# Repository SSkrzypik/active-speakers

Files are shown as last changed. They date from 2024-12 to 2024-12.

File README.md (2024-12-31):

The project involves active speakers inspired by the Tonsil Maestro S. The power amplifier driving the speakers consists of four TDA7294 chips. For the crossover network and sound tone adjustments, a DSP Adau1701 is used. The power supply is sourced from a toroidal transformer, and the section is enhanced with an EMI filter and a soft-start circuit. Additionally, the master speaker features an extra board that controls an OLED display and serves as a Bluetooth audio source.

qW7aE1r
IkFJe0s
2Np26g0
At0ftzc

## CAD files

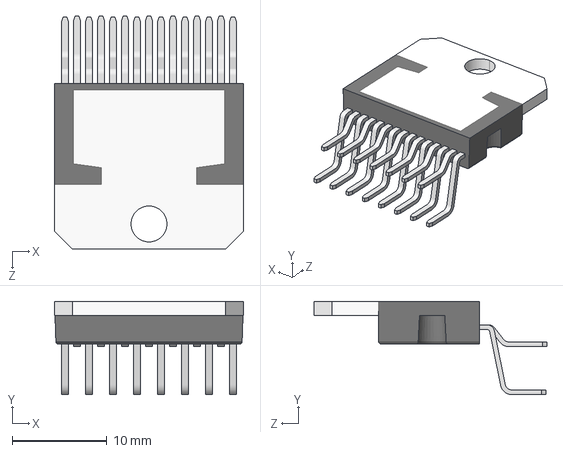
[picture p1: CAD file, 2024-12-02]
hardware/amplifier/3d/MULTIWATT15.STEP
20.0 x 9.88 x 24.6 mm

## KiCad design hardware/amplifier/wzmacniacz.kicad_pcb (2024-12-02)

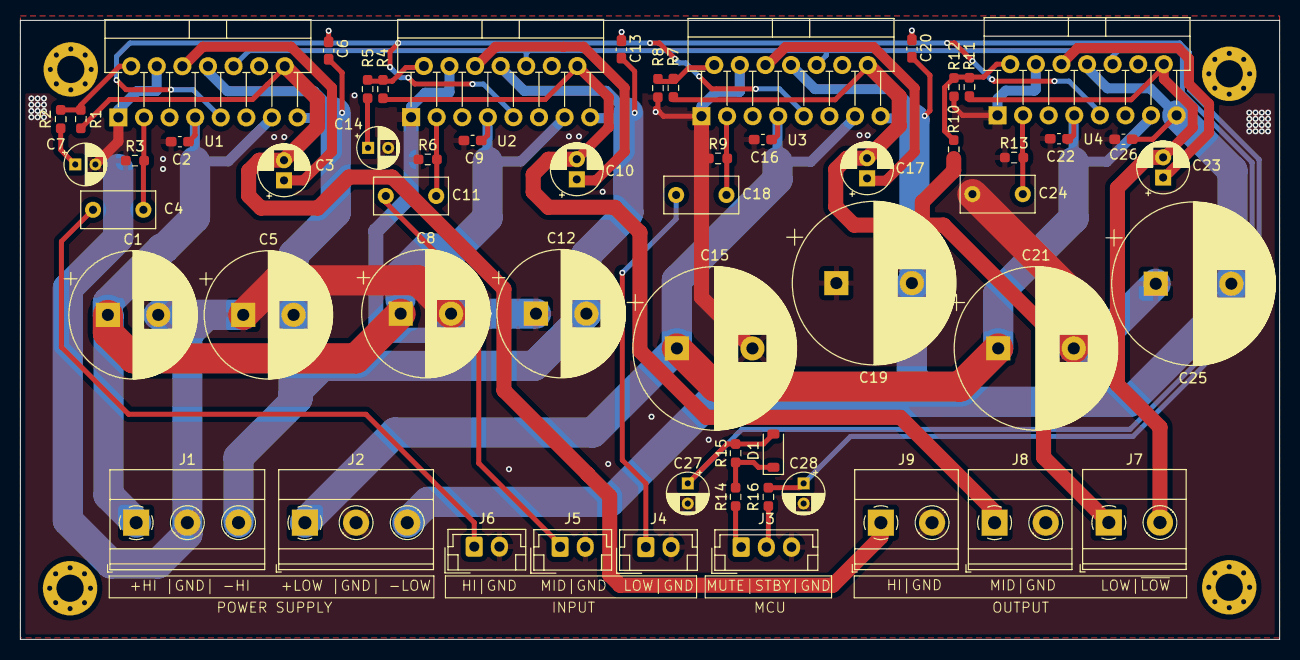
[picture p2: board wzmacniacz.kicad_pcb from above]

Board: 2 copper layers, 125.0 x 61.4 mm, 62 parts (0 on the bottom side), 31 nets.

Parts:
C1, C5, C8, C12: 1000uF; CP_Radial_D12.5mm_P5.00mm
C2, C6, C9, C13, C16, C20, C22, C26: 100nF; C_0603_1608Metric_Pad1.08x0.95mm_HandSolder
C3, C10, C17, C23: 22uF; CP_Radial_D5.0mm_P2.00mm
C4, C11: 470nF; C_Rect_L7.2mm_W3.5mm_P5.00mm_FKS2_FKP2_MKS2_MKP2
C7, C14, C27, C28: 22uF; CP_Radial_D4.0mm_P2.00mm
C15, C19, C21, C25: 2200uF; CP_Radial_D16.0mm_P7.50mm
C18, C24: 560nF; C_Rect_L7.2mm_W3.5mm_P5.00mm_FKS2_FKP2_MKS2_MKP2
D1: 1N4148WT; D_SOD-123
H1, H2, H3, H4: MountingHole; MountingHole_2.7mm_Pad_Via
J1, J2: Conn_01x03; TerminalBlock_Phoenix_MKDS-1,5-3-5.08_1x03_P5.08mm_Horizont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
J3: Conn_01x03; JST_EH_B3B-EH-A_1x03_P2.50mm_Vertical
J4, J5, J6: Conn_01x02; JST_EH_B2B-EH-A_1x02_P2.50mm_Vertical
J7, J8, J9: Conn_01x02; TerminalBlock_Phoenix_MKDS-1,5-2-5.08_1x02_P5.08mm_Horizont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
R1, R3, R4, R6, R7, R9, R10, R11, R13, R16: 22K; R_0603_1608Metric_Pad0.98x0.95mm_HandSolder
R2, R5, R8, R12: 680; R_0603_1608Metric_Pad0.98x0.95mm_HandSolder
R14: 10K; R_0603_1608Metric_Pad0.98x0.95mm_HandSolder
R15: 30K; R_0603_1608Metric_Pad0.98x0.95mm_HandSolder
U1, U2, U3, U4: TDA7294; TO-220-15_P2.54x2.54mm_StaggerOdd_Lead4.58mm_Vertical

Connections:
+VS_HI/MID: C1.1, C2.2, C8.1, C9.2, J1.1, U1.7 (+Vs), U1.13 (+Vs), U2.7 (+Vs), U2.13 (+Vs)
+VS_LOW: C15.1, C16.2, C21.1, C22.2, J2.1, U3.7 (+Vs), U3.13 (+Vs), U4.7 (+Vs), U4.13 (+Vs)
-VS_HI/MID: C5.2, C6.2, C12.2, C13.2, J1.3, U1.8 (-Vs), U1.15 (-Vs), U2.8 (-Vs), U2.15 (-Vs)
-VS_LOW: C19.2, C20.2, C25.2, C26.2, J2.3, U3.8 (-Vs), U3.15 (-Vs), U4.8 (-Vs), U4.15 (-Vs)
/CTRL_MUTE: J3.1, R14.1
/CTRL_STBY: J3.2, R16.2
/IN_HIGH: C4.1, J6.1
/IN_LOW: C18.1, J4.1
/IN_MID: C11.1, J5.1
/MUTE: C27.1, D1.2 (A), R15.2, U1.10 (MUTE), U2.10 (MUTE), U3.10 (MUTE), U4.10 (MUTE)
/OUT_HIGH: C3.2, J9.1, R1.1, U1.14
/OUT_LOW+: C17.2, J7.1, R7.1, R10.1, U3.14
/OUT_LOW-: C23.2, J7.2, R11.1, U4.14
/OUT_MID: C10.2, J8.1, R4.1, U2.14
/STBY: C28.1, R16.1, U1.9 (STBY), U2.9 (STBY), U3.9 (STBY), U4.9 (STBY)
GND: C1.2, C2.1, C5.1, C6.1, C7.2, C8.2, C9.1, C12.1, C13.1, C14.2, C15.2, C16.1, C19.1, C20.1, C21.2, C22.1, C24.1, C25.1, C26.1, C27.2, C28.2, J1.2, J2.2, J3.3, J4.2, J5.2, J6.2, J8.2, J9.2, R3.1, R6.1, R8.1, R9.1, R12.1, R13.1, U1.1 (SGND), U1.4 (SIG_GND), U2.1 (SGND), U2.4 (SIG_GND), U3.1 (SGND), U3.4 (SIG_GND), U4.1 (SGND), U4.4 (SIG_GND)
unnamed: C7.1, R2.1
unnamed: C14.1, R5.1
unnamed: D1.1 (K), R14.2, R15.1
unnamed: C4.2, R3.2, U1.3 (+)
unnamed: R1.2, R2.2, U1.2 (-)
unnamed: C3.1, U1.6 (BOOT)
unnamed: C11.2, R6.2, U2.3 (+)
unnamed: R4.2, R5.2, U2.2 (-)
unnamed: C10.1, U2.6 (BOOT)
unnamed: C18.2, R9.2, U3.3 (+)
unnamed: R7.2, R8.2, U3.2 (-)
unnamed: C17.1, U3.6 (BOOT)
unnamed: C24.2, R13.2, U4.3 (+)
unnamed: R10.2, R11.2, R12.2, U4.2 (-)
unnamed: C23.1, U4.6 (BOOT)

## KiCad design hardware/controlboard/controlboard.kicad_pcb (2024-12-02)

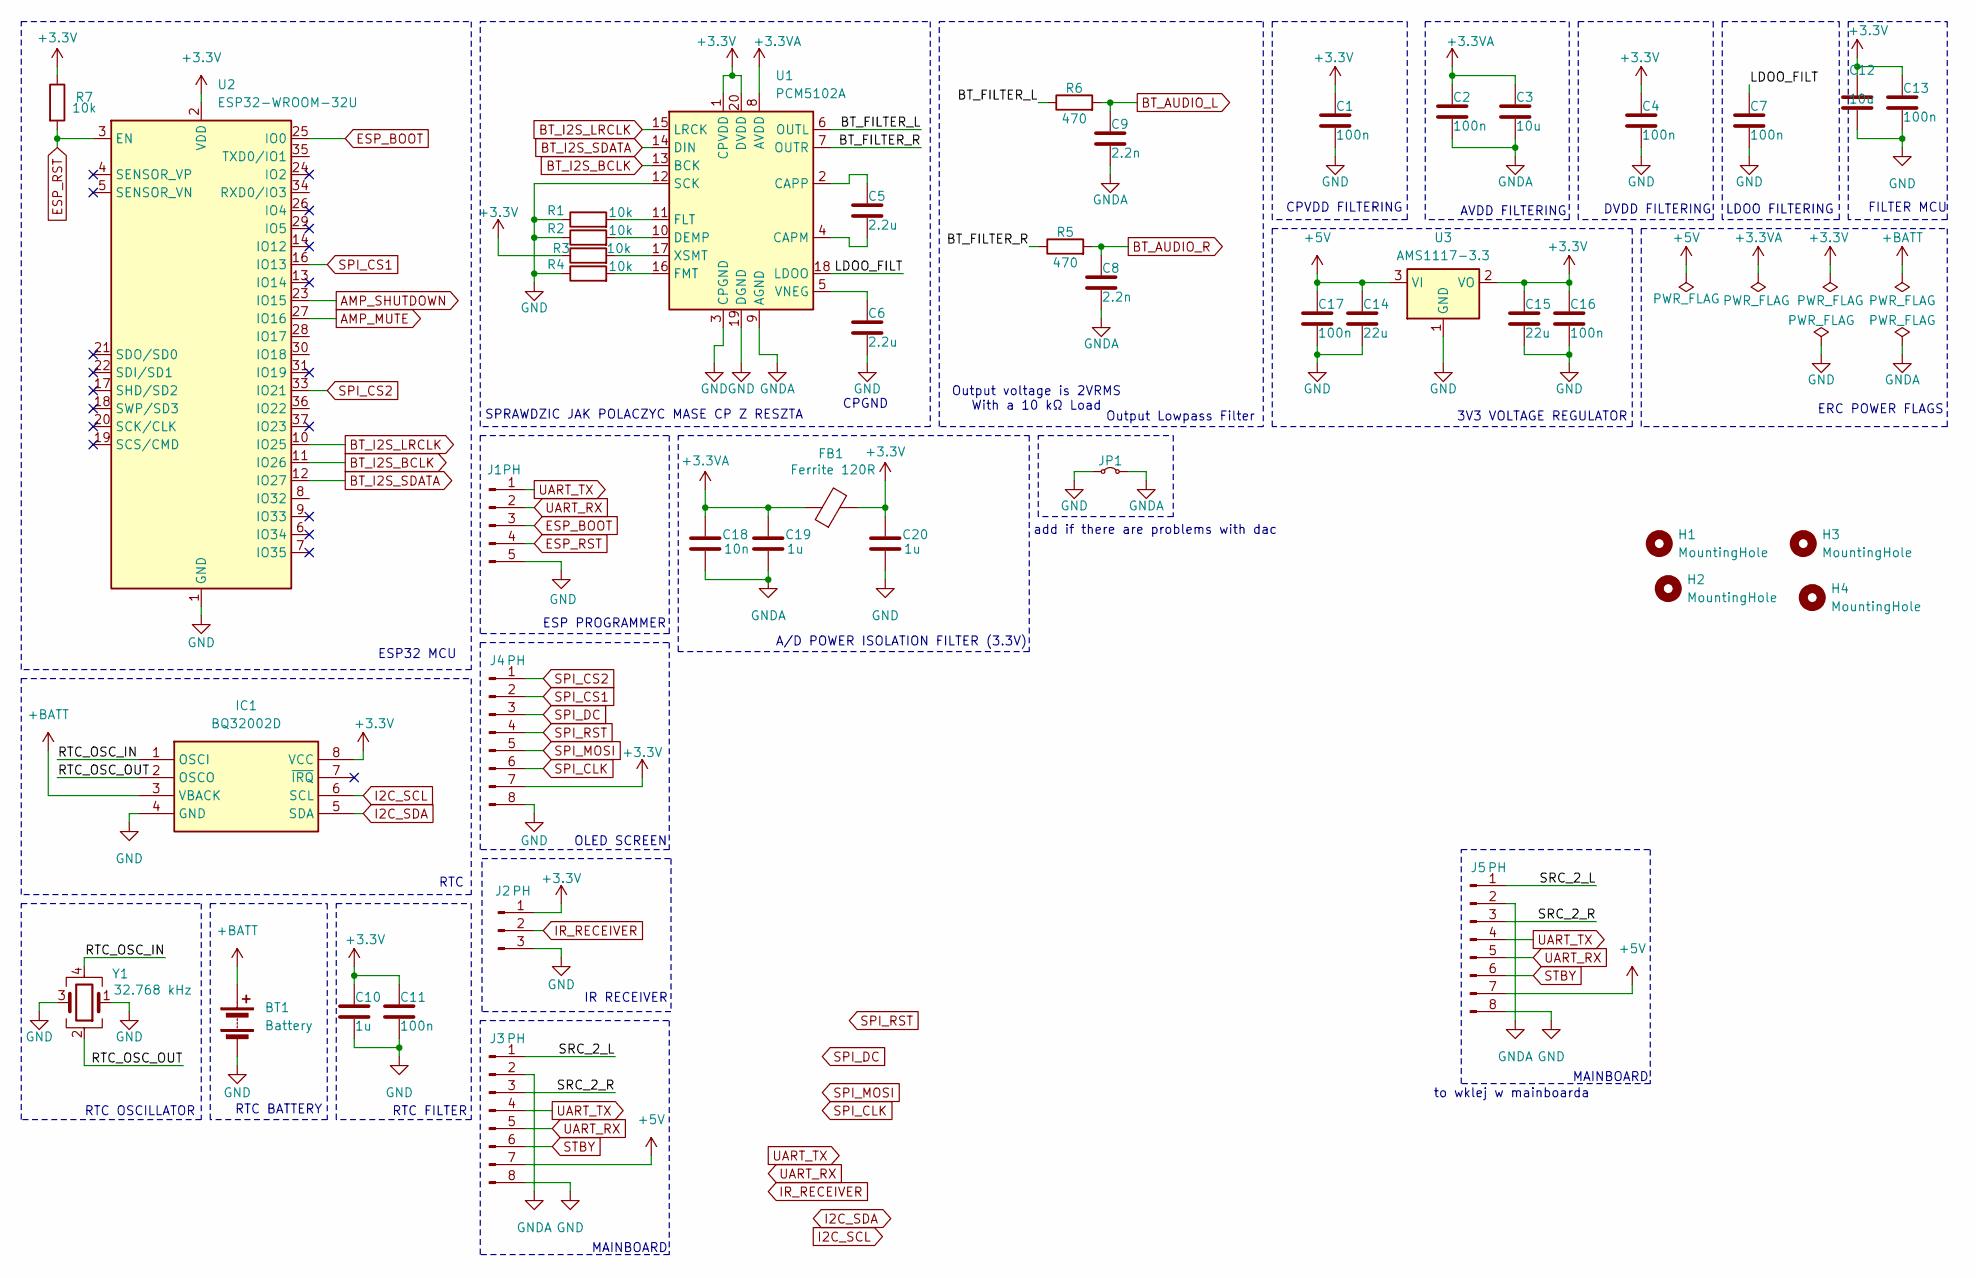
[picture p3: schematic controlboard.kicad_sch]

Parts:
BT1: Battery; BatteryHolder_LINX_BAT-HLD-012-SMT
C1, C2, C4, C7, C11, C13, C16, C17: 100n; C_0603_1608Metric_Pad1.08x0.95mm_HandSolder
C3, C12: 10u; C_0603_1608Metric_Pad1.08x0.95mm_HandSolder
C5, C6: 2.2u; C_0603_1608Metric_Pad1.08x0.95mm_HandSolder
C8, C9: 2.2n; C_0603_1608Metric_Pad1.08x0.95mm_HandSolder
C10, C19, C20: 1u; C_0603_1608Metric_Pad1.08x0.95mm_HandSolder
C14, C15: 22u; C_0603_1608Metric_Pad1.08x0.95mm_HandSolder
C18: 10n; C_0603_1608Metric_Pad1.08x0.95mm_HandSolder
FB1: Ferrite 120R; L_0805_2012Metric_Pad1.05x1.20mm_HandSolder
H1, H2, H3, H4: MountingHole; MountingHole_3.2mm_M3
IC1: BQ32002D; SOIC-8_3.9x4.9mm_P1.27mm; Mouser Part Number 595-BQ32002D
J1: PH; JST_PH_B5B-PH-K_1x05_P2.00mm_Vertical
J2: PH; JST_PH_B3B-PH-K_1x03_P2.00mm_Vertical
J3, J4: PH; JST_PH_B8B-PH-K_1x08_P2.00mm_Vertical
J5: PH
JP1: Jumper_2_Small_Bridged; R_1210_3225Metric_Pad1.30x2.65mm_HandSolder
R1, R2, R3, R4, R7: 10k; R_0603_1608Metric_Pad0.98x0.95mm_HandSolder
R5, R6: 470; R_0603_1608Metric_Pad0.98x0.95mm_HandSolder
U1: PCM5102A; TSSOP-20_4.4x6.5mm_P0.65mm
U2: ESP32-WROOM-32U
U3: AMS1117-3.3; SOT-223-3_TabPin2
Y1: 32.768 kHz; Crystal_SMD_7050-4Pin_7.0x5.0mm

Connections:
+3.3V: C1.1, C4.1, C10.1, C11.1, C12.1, C13.1, C15.1, C16.1, C20.1, FB1.2, IC1.8 (VCC), J2.1, J4.7, R3.1, R7.1, U1.1 (CPVDD), U1.20 (DVDD), U2.2 (VDD), U3.2 (VO)
+3.3VA: C2.1, C3.1, C18.1, C19.1, FB1.1, U1.8 (AVDD)
+5V: C14.1, C17.1, J3.7, J5.7, U3.3 (VI)
+BATT: BT1.1 (+), IC1.3 (VBACK)
/BT_FILTER_L: R6.1, U1.6 (OUTL)
/BT_FILTER_R: R5.1, U1.7 (OUTR)
/LDOO_FILT: C7.1, U1.18 (LDOO)
/RTC_OSC_IN: IC1.1 (OSCI), Y1.4
/RTC_OSC_OUT: IC1.2 (OSCO), Y1.2
/SRC_2_L: J3.1, J5.1
/SRC_2_R: J3.3, J5.3
AMP_MUTE: U2.27 (IO16)
AMP_SHUTDOWN: U2.23 (IO15)
BT_AUDIO_L: C9.1, R6.2
BT_AUDIO_R: C8.1, R5.2
BT_I2S_BCLK: U1.13 (BCK), U2.11 (IO26)
BT_I2S_LRCLK: U1.15 (LRCK), U2.10 (IO25)
BT_I2S_SDATA: U1.14 (DIN), U2.12 (IO27)
ESP_BOOT: J1.3, U2.25 (IO0)
ESP_RST: J1.4, R7.2, U2.3 (EN)
GND: BT1.2 (-), C1.2, C4.2, C6.2, C7.2, C10.2, C11.2, C12.2, C13.2, C14.2, C15.2, C16.2, C17.2, C20.2, IC1.4 (GND), J1.5, J2.3, J3.8, J4.8, J5.8, JP1.1 (A), R1.1, R2.1, R4.1, U1.3 (CPGND), U1.12 (SCK), U1.19 (DGND), U2.1 (GND), U2.15 (GND), U2.38 (GND), U2.39 (GND), U3.1 (GND), Y1.1, Y1.3
GNDA: C2.2, C3.2, C8.2, C9.2, C18.2, C19.2, J3.2, J5.2, JP1.2 (B), U1.9 (AGND)
I2C_SCL: IC1.6 (SCL)
I2C_SDA: IC1.5 (SDA)
IR_RECEIVER: J2.2
unnamed: C5.2, U1.4 (CAPM)
unnamed: C5.1, U1.2 (CAPP)
unnamed: R2.2, U1.10 (DEMP)
unnamed: R1.2, U1.11 (FLT)
unnamed: R4.2, U1.16 (FMT)
unnamed: C6.1, U1.5 (VNEG)
unnamed: R3.2, U1.17 (XSMT)
SPI_CLK: J4.6
SPI_CS1: J4.2, U2.16 (IO13)
SPI_CS2: J4.1, U2.33 (IO21)
SPI_DC: J4.3
SPI_MOSI: J4.5
SPI_RST: J4.4
STBY: J3.6, J5.6
UART_RX: J1.2, J3.5, J5.5
UART_TX: J1.1, J3.4, J5.4

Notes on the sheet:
ESP32 MCU
ERC POWER FLAGS
RTC FILTER
AVDD FILTERING
ESP PROGRAMMER
MAINBOARD
FILTER MCU
Output voltage is 2VRMS With a 10 kΩ Load
to wklej w mainboarda
RTC OSCILLATOR
3V3 VOLTAGE REGULATOR
RTC BATTERY
RTC
CPGND
add if there are problems with dac
OLED SCREEN
IR RECEIVER
Output Lowpass Filter
CPVDD FILTERING
LDOO FILTERING
SPRAWDZIC JAK POLACZYC MASE CP Z RESZTA
DVDD FILTERING
A/D POWER ISOLATION FILTER (3.3V)

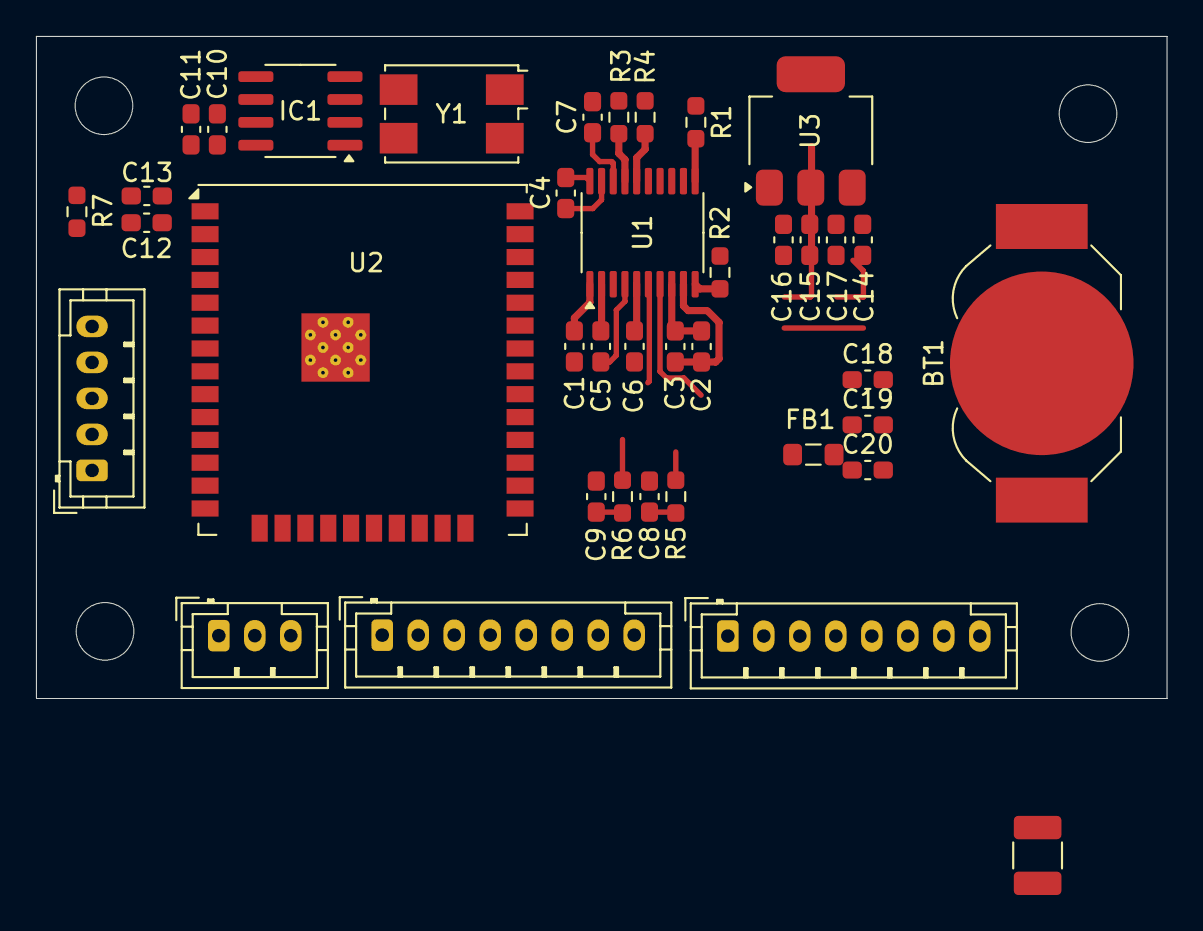
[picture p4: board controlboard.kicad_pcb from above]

Board: 2 copper layers, 62.8 x 36.8 mm, 43 parts (0 on the bottom side), 29 nets.

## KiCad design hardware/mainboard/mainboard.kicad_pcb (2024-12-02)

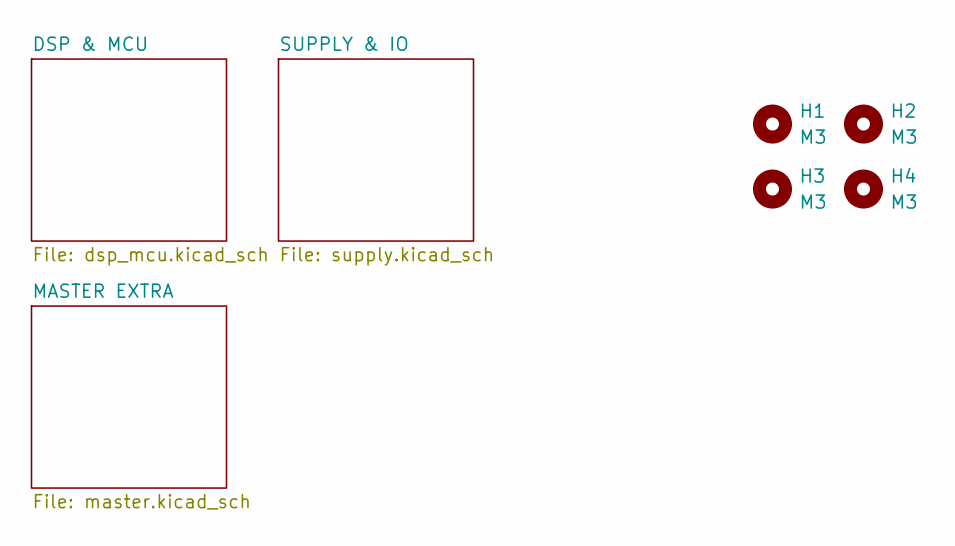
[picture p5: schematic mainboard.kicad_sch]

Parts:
H1, H2, H3, H4: M3; MountingHole_2.7mm_M2.5

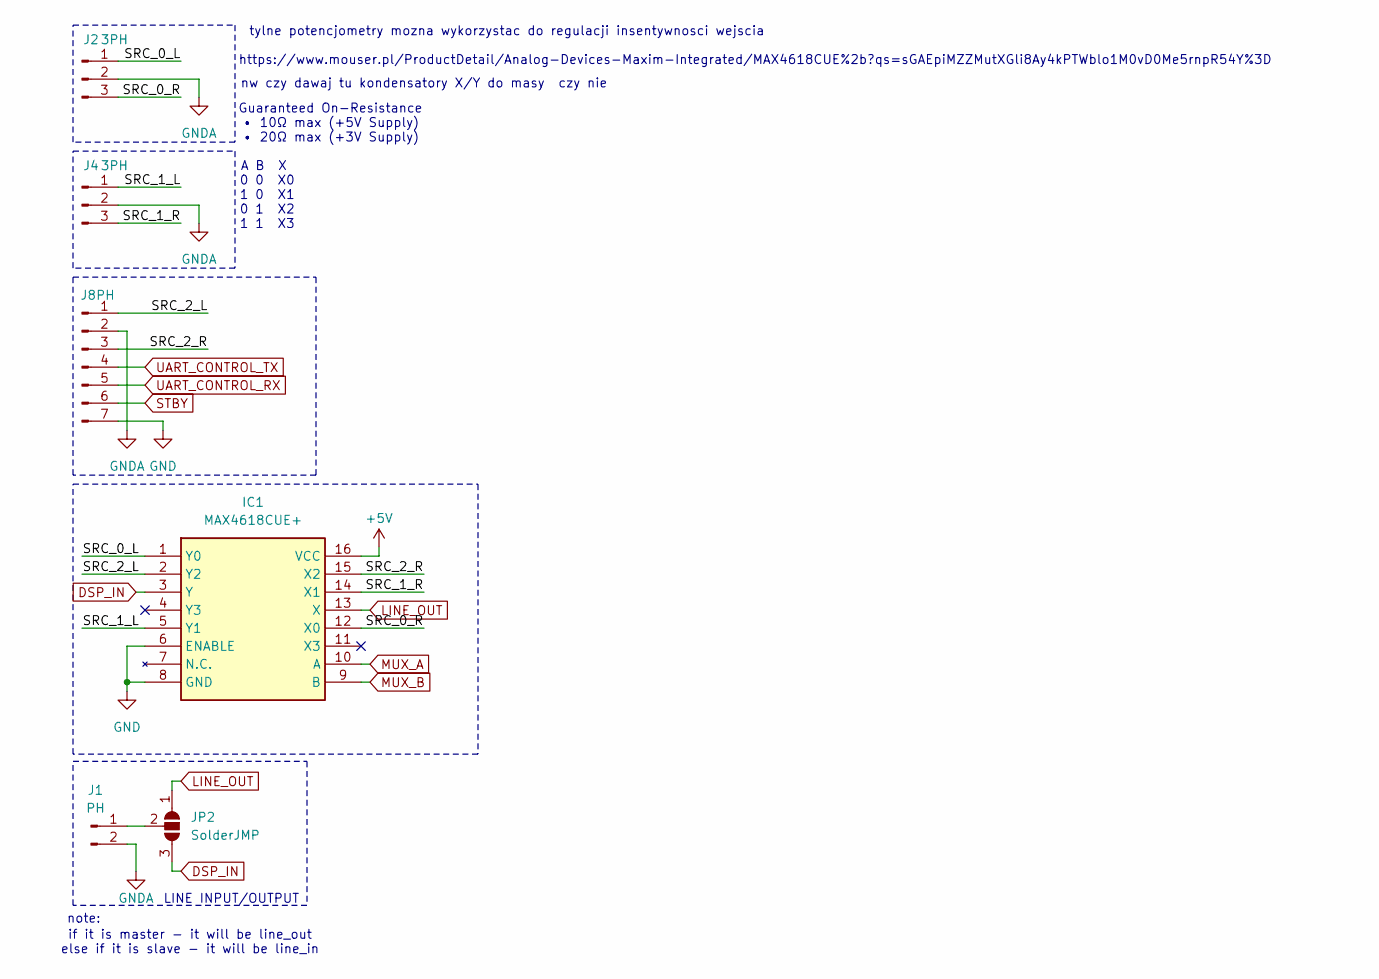
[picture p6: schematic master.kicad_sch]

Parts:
IC1: MAX4618CUE+; SOP65P640X110-16N; Mouser Part Number 700-MAX4618CUE
J1: PH; JST_PH_B2B-PH-K_1x02_P2.00mm_Vertical
J2, J4: 3PH; JST_PH_B3B-PH-K_1x03_P2.00mm_Vertical
J8: PH; JST_PH_B7B-PH-K_1x07_P2.00mm_Vertical
JP2: SolderJMP

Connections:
+5V: IC1.16 (VCC); also elsewhere on the board
/MASTER EXTRA/SRC_0_L: IC1.1 (Y0), J2.1
/MASTER EXTRA/SRC_0_R: IC1.12 (X0), J2.3
/MASTER EXTRA/SRC_1_L: IC1.5 (Y1), J4.1
/MASTER EXTRA/SRC_1_R: IC1.14 (X1), J4.3
/MASTER EXTRA/SRC_2_L: IC1.2 (Y2), J8.1
/MASTER EXTRA/SRC_2_R: IC1.15 (X2), J8.3
DSP_IN: IC1.3 (Y), JP2.3 (B); also elsewhere on the board
GND: IC1.6 (ENABLE), IC1.8 (GND), J8.7; also elsewhere on the board
GNDA: J1.2, J2.2, J4.2, J8.2; also elsewhere on the board
LINE_OUT: IC1.13 (X), JP2.1 (A)
MUX_A: IC1.10 (A); also elsewhere on the board
MUX_B: IC1.9 (B); also elsewhere on the board
unnamed: J1.1, JP2.2 (C)
STBY: J8.6; also elsewhere on the board
UART_CONTROL_RX: J8.5; also elsewhere on the board
UART_CONTROL_TX: J8.4; also elsewhere on the board

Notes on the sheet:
https://www.mouser.pl/ProductDetail/Analog-Devices-Maxim-Integrated/MAX4618CUE%2b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
tylne potencjometry mozna wykorzystac do regulacji insentywnosci wejscia
LINE INPUT/OUTPUT
Guaranteed On-Resistance • 10Ω max (+5V Supply) • 20Ω max (+3V Supply)
A B X 0 0 X0 1 0 X1 0 1 X2 1 1 X3
note:
nw czy dawaj tu kondensatory X/Y do masy czy nie
if it is master - it will be line_out else if it is slave - it will be line_in

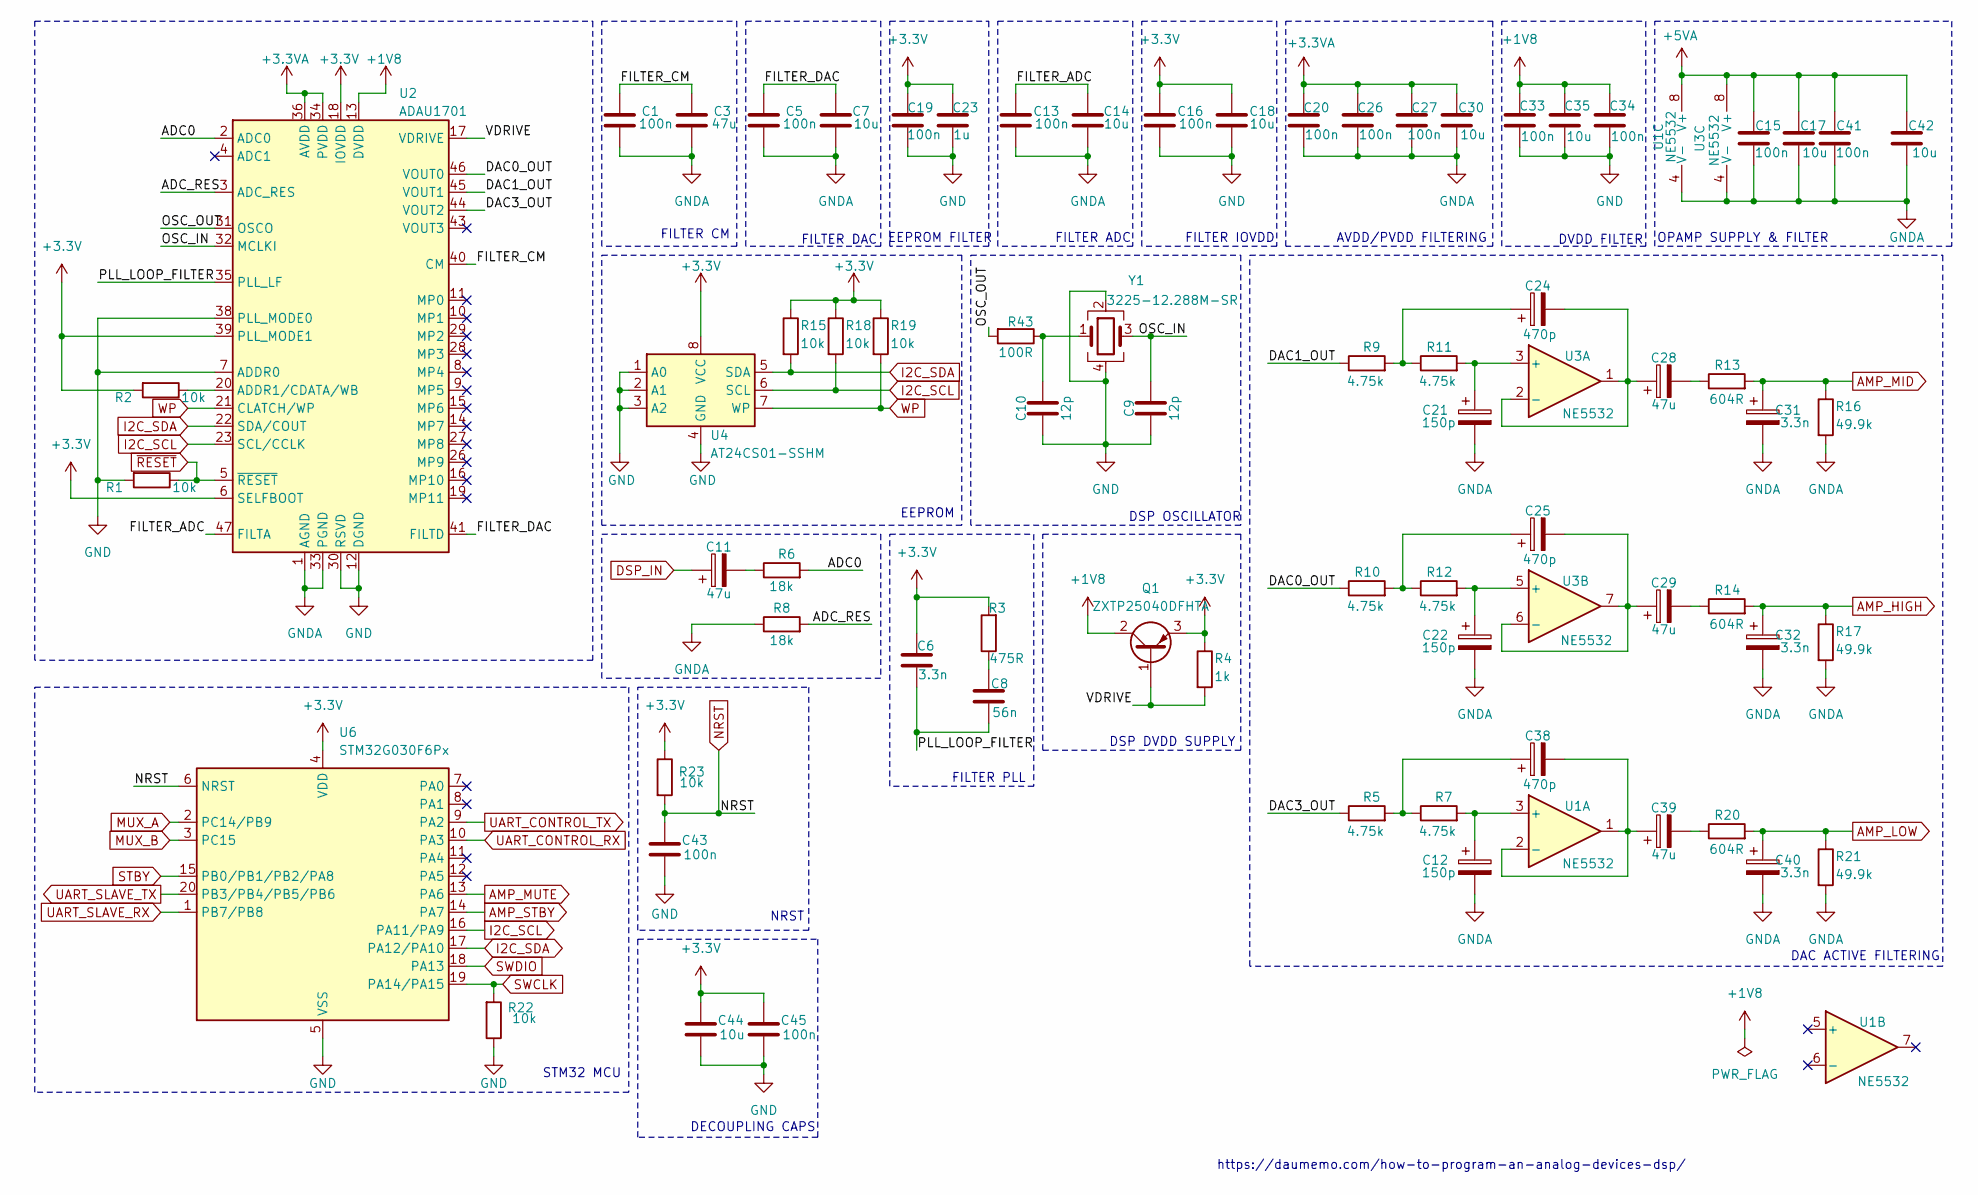
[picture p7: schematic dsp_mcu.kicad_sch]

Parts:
C1, C5, C13, C15, C16, C19, C20, C26, C27, C33, C34, C41, C43, C45: 100n; C_0603_1608Metric_Pad1.08x0.95mm_HandSolder
C3, C11, C28, C29, C39: 47u; C_0603_1608Metric_Pad1.08x0.95mm_HandSolder
C6, C31, C32, C40: 3.3n; C_0603_1608Metric_Pad1.08x0.95mm_HandSolder
C7, C14, C17, C18, C30, C35, C42, C44: 10u; C_0603_1608Metric_Pad1.08x0.95mm_HandSolder
C8: 56n; C_0603_1608Metric_Pad1.08x0.95mm_HandSolder
C9, C10: 12p; C_0603_1608Metric_Pad1.08x0.95mm_HandSolder
C12, C21, C22: 150p; C_0603_1608Metric_Pad1.08x0.95mm_HandSolder
C23: 1u; C_0603_1608Metric_Pad1.08x0.95mm_HandSolder
C24, C25, C38: 470p; C_0603_1608Metric_Pad1.08x0.95mm_HandSolder
Q1: ZXTP25040DFHTA; SOT-23_Handsoldering
R1, R2, R15, R18, R19, R22, R23: 10k; R_0603_1608Metric_Pad0.98x0.95mm_HandSolder
R3: 475R; R_0603_1608Metric_Pad0.98x0.95mm_HandSolder
R4: 1k; R_0603_1608Metric_Pad0.98x0.95mm_HandSolder
R5, R7, R9, R10, R11, R12: 4.75k; R_0603_1608Metric_Pad0.98x0.95mm_HandSolder
R6, R8: 18k; R_0603_1608Metric_Pad0.98x0.95mm_HandSolder
R13, R14, R20: 604R; R_0603_1608Metric_Pad0.98x0.95mm_HandSolder
R16, R17, R21: 49.9k; R_0603_1608Metric_Pad0.98x0.95mm_HandSolder
R43: 100R; R_0603_1608Metric_Pad0.98x0.95mm_HandSolder
U1, U3: NE5532; SOIC-8-1EP_3.9x4.9mm_P1.27mm_EP2.29x3mm
U2: ADAU1701; LQFP-48-1EP_7x7mm_P0.5mm_EP3.6x3.6mm_ThermalVias
U4: AT24CS01-SSHM; SOIC-8-1EP_3.9x4.9mm_P1.27mm_EP2.41x3.3mm_ThermalVias
U6: STM32G030F6Px; TSSOP-20_4.4x6.5mm_P0.65mm
Y1: 3225-12.288M-SR; Crystal_SMD_SeikoEpson_TSX3225-4Pin_3.2x2.5mm

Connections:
+1V8: C33.1, C34.1, C35.1, Q1.2 (C), U2.13 (DVDD), U2.24 (DVDD)
+3.3V: C6.2, C16.1, C18.1, C19.1, C23.1, C44.1, C45.1, Q1.3 (E), R2.2, R3.2, R4.1, R15.1, R18.1, R19.1, R23.1, U2.6 (SELFBOOT), U2.18 (IOVDD), U2.39 (PLL_MODE1), U4.8 (VCC), U6.4 (VDD); also elsewhere on the board
+3.3VA: C20.1, C26.1, C27.1, C30.1, U2.34 (PVDD), U2.36 (AVDD), U2.48 (AVDD); also elsewhere on the board
+5VA: C15.1, C17.1, C41.1, C42.1, U1.8 (V+), U3.8 (V+); also elsewhere on the board
/DSP & MCU/ADC0: R6.2, U2.2 (ADC0)
/DSP & MCU/ADC_RES: R8.2, U2.3 (ADC_RES)
/DSP & MCU/DAC0_OUT: R10.1, U2.46 (VOUT0)
/DSP & MCU/DAC1_OUT: R9.1, U2.45 (VOUT1)
/DSP & MCU/DAC3_OUT: R5.1, U2.44 (VOUT2)
/DSP & MCU/FILTER_ADC: C13.1, C14.1, U2.47 (FILTA)
/DSP & MCU/FILTER_CM: C1.1, C3.1, U2.40 (CM)
/DSP & MCU/FILTER_DAC: C5.1, C7.1, U2.41 (FILTD)
/DSP & MCU/OSC_IN: C9.2, U2.32 (MCLKI), Y1.3
/DSP & MCU/OSC_OUT: R43.2, U2.31 (OSCO)
/DSP & MCU/PLL_LOOP_FILTER: C6.1, C8.1, U2.35 (PLL_LF)
/DSP & MCU/VDRIVE: Q1.1 (B), R4.2, U2.17 (VDRIVE)
AMP_HIGH: C32.1, R14.2, R17.1; also elsewhere on the board
AMP_LOW: C40.1, R20.2, R21.1; also elsewhere on the board
AMP_MID: C31.1, R13.2, R16.1; also elsewhere on the board
AMP_MUTE: U6.13 (PA6); also elsewhere on the board
AMP_STBY: U6.14 (PA7); also elsewhere on the board
DSP_IN: C11.1; also elsewhere on the board
GND: C9.1, C10.1, C16.2, C18.2, C19.2, C23.2, C33.2, C34.2, C35.2, C43.2, C44.2, C45.2, R1.2, R22.1, U2.7 (ADDR0), U2.12 (DGND), U2.25 (DGND), U2.30 (RSVD), U2.38 (PLL_MODE0), U4.1 (A0), U4.2 (A1), U4.3 (A2), U4.4 (GND), U6.5 (VSS), Y1.2, Y1.4; also elsewhere on the board
GNDA: C1.2, C3.2, C5.2, C7.2, C12.2, C13.2, C14.2, C15.2, C17.2, C20.2, C21.2, C22.2, C26.2, C27.2, C30.2, C31.2, C32.2, C40.2, C41.2, C42.2, R8.1, R16.2, R17.2, R21.2, U1.4 (V-), U2.1 (AGND), U2.33 (PGND), U2.37 (AGND), U2.42 (AGND), U3.4 (V-); also elsewhere on the board
I2C_SCL: R18.2, U2.23 (SCL/CCLK), U4.6 (SCL), U6.16 (PA11/PA9); also elsewhere on the board
I2C_SDA: R15.2, U2.22 (SDA/COUT), U4.5 (SDA), U6.17 (PA12/PA10); also elsewhere on the board
MUX_A: U6.2 (PC14/PB9); also elsewhere on the board
MUX_B: U6.3 (PC15); also elsewhere on the board
NRST: C43.1, R23.2, U6.6 (NRST); also elsewhere on the board
unnamed: C8.2, R3.1
unnamed: C10.2, R43.1, Y1.1
unnamed: C11.2, R6.1
unnamed: C24.1, R9.2, R11.1
unnamed: C25.1, R10.2, R12.1
unnamed: C28.2, R13.1
unnamed: C29.2, R14.1
unnamed: C38.1, R5.2, R7.1
unnamed: C39.2, R20.1
unnamed: C12.1, R7.2, U1.3 (+)
unnamed: C38.2, C39.1, U1.1, U1.2 (-)
unnamed: R2.1, U2.20 (ADDR1/CDATA/WB)
unnamed: C21.1, R11.2, U3.3 (+)
unnamed: C24.2, C28.1, U3.1, U3.2 (-)
unnamed: C22.1, R12.2, U3.5 (+)
unnamed: C25.2, C29.1, U3.6 (-), U3.7
STBY: U6.15 (PB0/PB1/PB2/PA8); also elsewhere on the board
SWCLK: R22.2, U6.19 (PA14/PA15); also elsewhere on the board
SWDIO: U6.18 (PA13); also elsewhere on the board
UART_CONTROL_RX: U6.10 (PA3); also elsewhere on the board
UART_CONTROL_TX: U6.9 (PA2); also elsewhere on the board
UART_SLAVE_RX: U6.1 (PB7/PB8); also elsewhere on the board
UART_SLAVE_TX: U6.20 (PB3/PB4/PB5/PB6); also elsewhere on the board
WP: R19.2, U2.21 (CLATCH/WP), U4.7 (WP); also elsewhere on the board
~RESET: R1.1, U2.5 (~RESET); also elsewhere on the board

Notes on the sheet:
EEPROM
DAC ACTIVE FILTERING
DECOUPLING CAPS
AVDD/PVDD FILTERING
STM32 MCU
FILTER PLL
DVDD FILTER
https://daumemo.com/how-to-program-an-analog-devices-dsp/
FILTER DAC
OPAMP SUPPLY & FILTER
EEPROM FILTER
FILTER ADC
FILTER CM
DSP OSCILLATOR
FILTER IOVDD
DSP DVDD SUPPLY
NRST

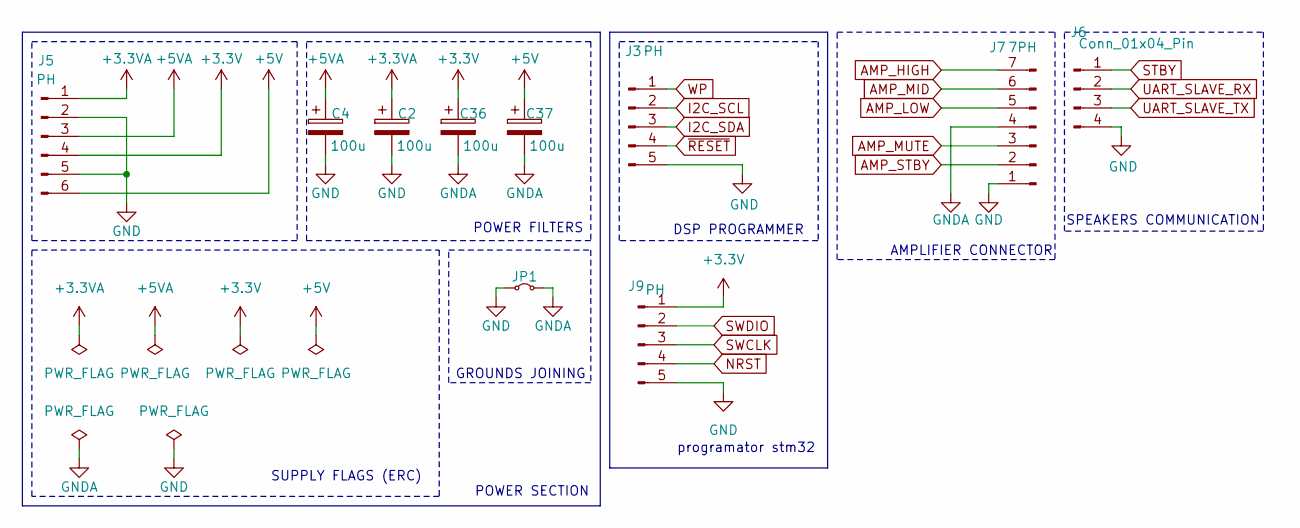
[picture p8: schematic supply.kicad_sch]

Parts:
C2, C4, C36, C37: 100u; CP_Elec_5x5.3
J3, J9: PH; JST_PH_B5B-PH-K_1x05_P2.00mm_Vertical
J5: PH; JST_PH_B6B-PH-K_1x06_P2.00mm_Vertical
J6: Conn_01x04_Pin; JST_PH_B4B-PH-K_1x04_P2.00mm_Vertical
J7: 7PH; JST_PH_B7B-PH-K_1x07_P2.00mm_Vertical
JP1: Jumper_2_Small_Bridged; R_1206_3216Metric_Pad1.30x1.75mm_HandSolder

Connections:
+3.3V: C36.1, J5.4, J9.1; also elsewhere on the board
+3.3VA: C2.1, J5.1; also elsewhere on the board
+5V: C37.1, J5.6; also elsewhere on the board
+5VA: C4.1, J5.3; also elsewhere on the board
AMP_HIGH: J7.7; also elsewhere on the board
AMP_LOW: J7.5; also elsewhere on the board
AMP_MID: J7.6; also elsewhere on the board
AMP_MUTE: J7.3; also elsewhere on the board
AMP_STBY: J7.2; also elsewhere on the board
GND: C2.2, C4.2, J3.5, J5.2, J5.5, J6.4, J7.1, J9.5, JP1.1 (A); also elsewhere on the board
GNDA: C36.2, C37.2, J7.4, JP1.2 (B); also elsewhere on the board
I2C_SCL: J3.2; also elsewhere on the board
I2C_SDA: J3.3; also elsewhere on the board
NRST: J9.4; also elsewhere on the board
STBY: J6.1; also elsewhere on the board
SWCLK: J9.3; also elsewhere on the board
SWDIO: J9.2; also elsewhere on the board
UART_SLAVE_RX: J6.2; also elsewhere on the board
UART_SLAVE_TX: J6.3; also elsewhere on the board
WP: J3.1; also elsewhere on the board
~RESET: J3.4; also elsewhere on the board

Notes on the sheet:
SUPPLY FLAGS (ERC)
programator stm32
GROUNDS JOINING
POWER SECTION
DSP PROGRAMMER
SPEAKERS COMMUNICATION
POWER FILTERS
AMPLIFIER CONNECTOR

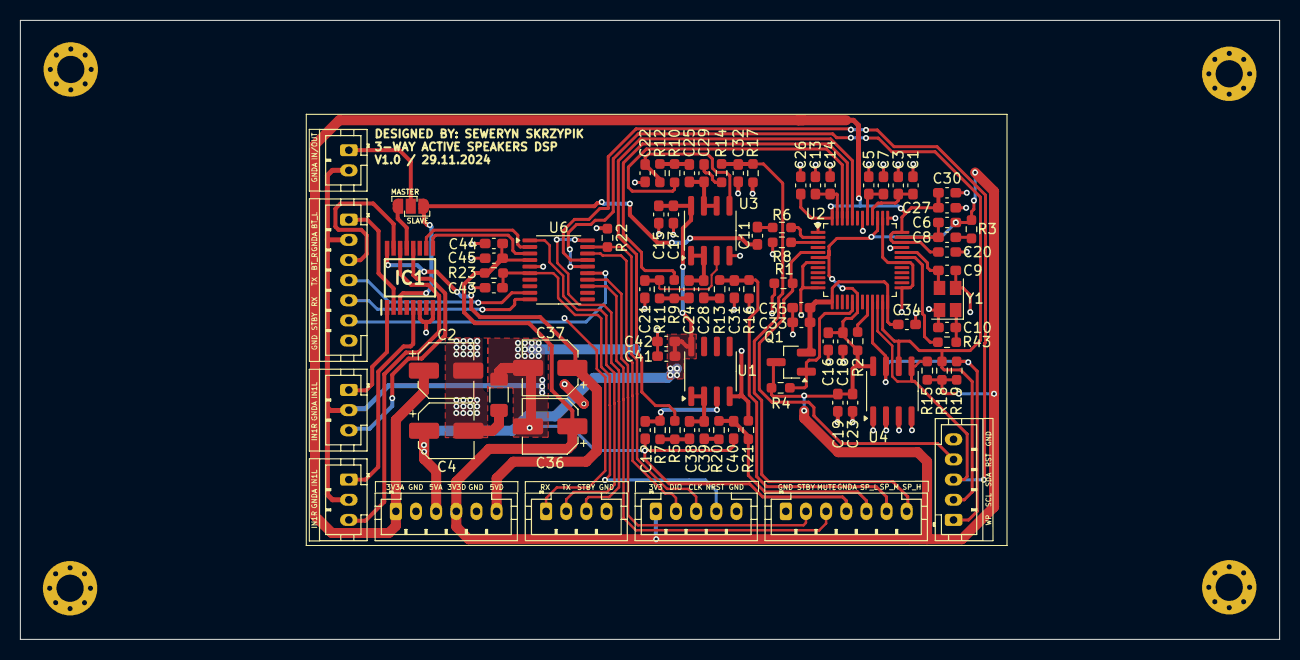
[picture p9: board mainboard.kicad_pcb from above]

Board: 2 copper layers, 125.0 x 61.4 mm, 92 parts (0 on the bottom side), 63 nets.
